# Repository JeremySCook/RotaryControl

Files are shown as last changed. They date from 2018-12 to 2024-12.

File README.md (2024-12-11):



# RotaryControl

*
*
### New Version: Enhanced [JC Pro Macro 2](https://www.tindie.com/products/jeremycook/jc-pro-macro-2-rotarygpio-macro-keyboard-kit/) for sale on Tindie with all kinds of fun features.
*
*

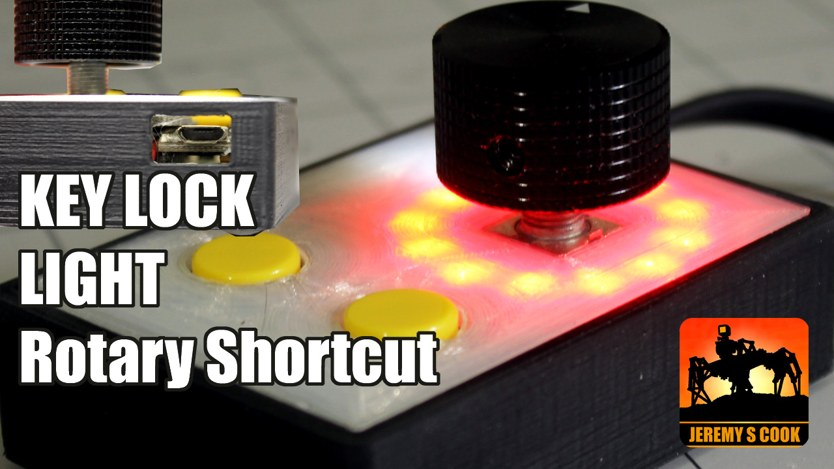
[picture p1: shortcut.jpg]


### Build videos

https://www.youtube.com/playlist?list=PLUSVaS5vtdgQBRD3hqpD_LZi0aTD-GRQe

### Purchased Electronics Needed

5x7 Perf board \
I2C Rotary Encoder: https://www.tindie.com/products/Saimon/i2cencoder-v2-connect-multiple-encoder-on-i2c-bus/ \
MellBell PICO: https://mellbell.cc/products/pico \
NeoPixel Ring: https://www.adafruit.com/product/1643 \
Rotary Encoder \
Encoder knob: https://www.ebay.com/itm/K9-0-25-Dia-Black-Aluminum-Rotary-Control-Potentiometer-Knob-25mm-x-15mm/253315168134 \
Pushbuttons \
Wire

### 3D Print Stuff

Clear PLA https://amzn.to/2MXi3qr (Amazon Affiliate) \
Black PLA https://amzn.to/31PlYd2 (Amazon Affiliate) \
Plasti Dip Spray https://amzn.to/34lU22f (Amazon Affiliate - not sure if this is the correct type)

### Wiring Diagram

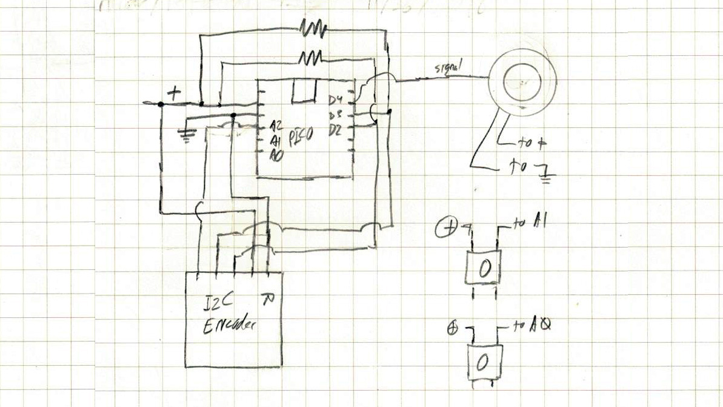
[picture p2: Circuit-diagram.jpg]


### Other Info

This post was helpful to figure out how to use the caps lock functionality: https://www.instructables.com/id/USB-Volume-Control-and-Caps-Lock-LED-Simple-Cheap-/ \
Code referenced in [Arrow Encoder article](https://www.arrow.com/en/research-and-events/articles/rotary-encoders-how-to-pair-with-an-arduino-board): https://github.com/JeremySCook/ArduinoEncoder



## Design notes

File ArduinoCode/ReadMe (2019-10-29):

Arduino Code including two i2c Libraries ((i2cEncoderLibV2.cpp and i2cEncoderLibV2.h)
that need to be placed in same directory as main code.

Rotary-shortcut-1-capslock.ino adds functionality for ring to light up blue when caps lock key is on.

Rotary-shortcut-3-locks-jog.ino gives an indication of caps lock, scroll lock, and num lock.
Does away with game functionality as shown in the demo video, but replaces it with a "jog" function
that adjusts volume up and down intermittently to keep computer awake (in case your power management is
acting screwy).

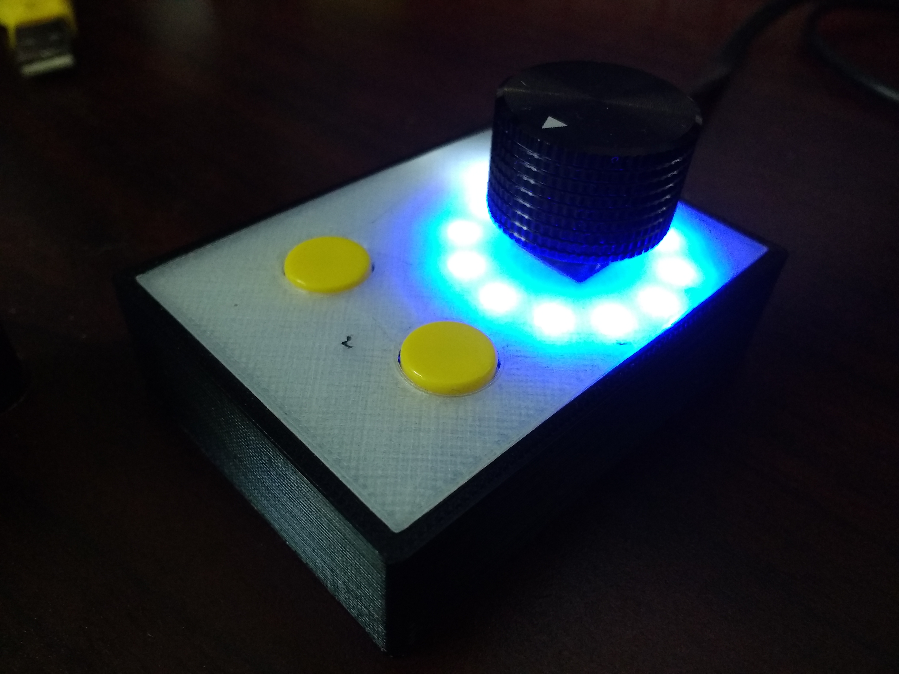
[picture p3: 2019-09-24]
rotary-caps.jpg

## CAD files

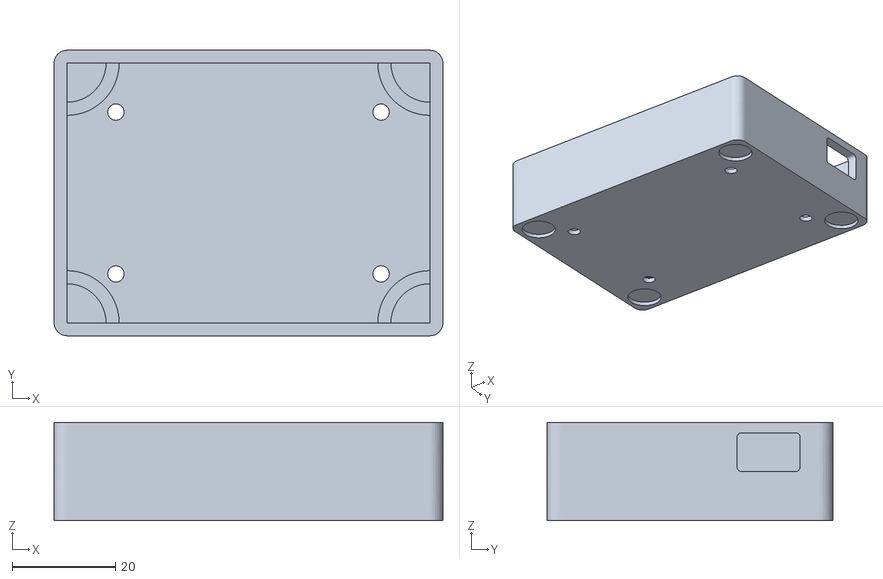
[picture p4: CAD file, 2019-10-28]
STL/shortcut-outer.stl
75.4 x 55.4 x 19.0

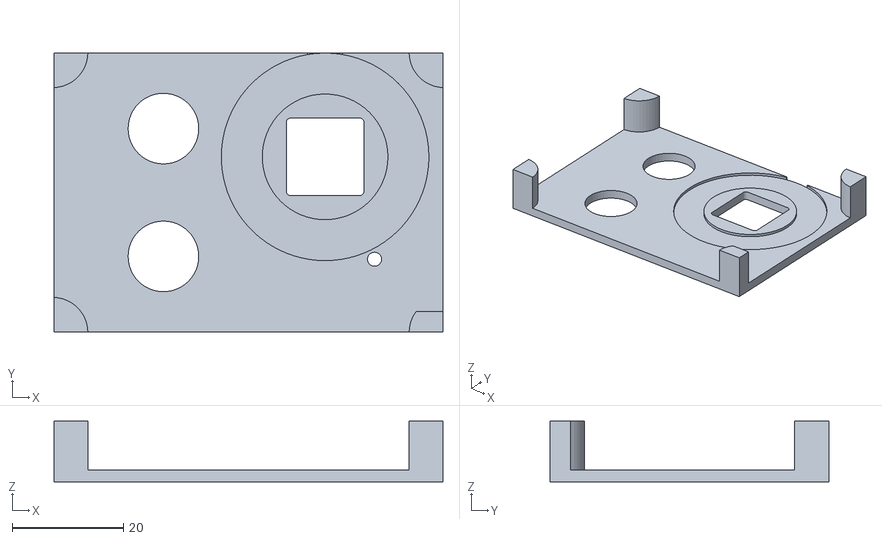
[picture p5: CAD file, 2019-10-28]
STL/shortcut-inner.stl
70.0 x 50.2 x 10.9

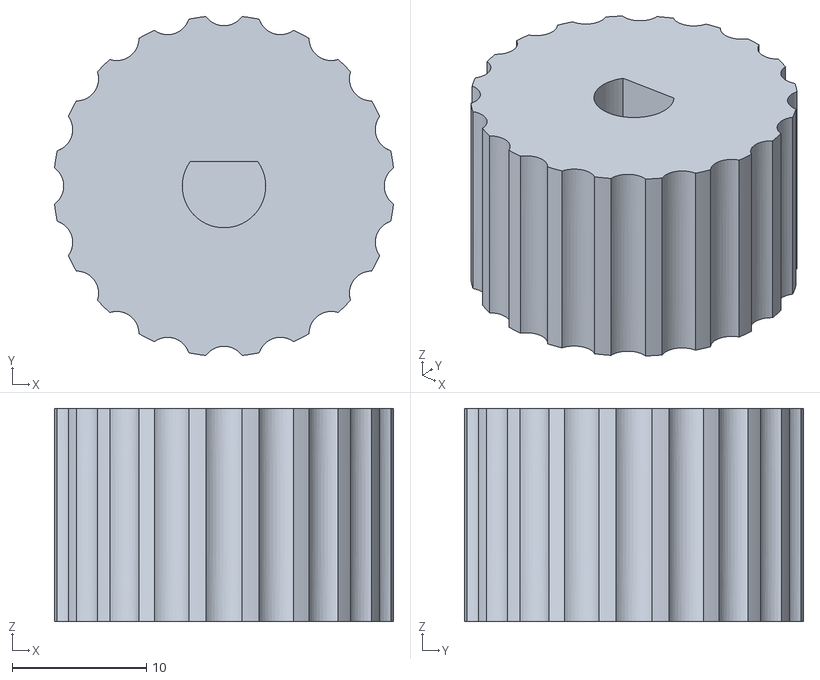
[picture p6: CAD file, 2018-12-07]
STL/Knob.stl
25.3 x 25.3 x 15.9

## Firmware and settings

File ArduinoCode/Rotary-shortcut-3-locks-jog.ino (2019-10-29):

//Need to include i2cEncoderLibV2.cpp and i2cEncoderLibV2.h in same directory

//Initial setup =============================================================================

#include <Wire.h>
#include "i2cEncoderLibV2.h"
#include <Adafruit_NeoPixel.h>
#ifdef __AVR__
#include <avr/power.h>
#endif
#include "HID-Project.h"

#define PINRGB  4
#define NUMPIXELSRGB  12

int xMovements[] = {-3, -8, -14, -16, -19, -19, -16, -14, -8, -3, 3, 8, 14, 16, 19, 19, 16, 14, 8, 3, -3};
int yMovements[] = {19, 16, 14, 8, 3, -3, -8, -14, -16, -19, -19, -16, -14, -8, -3, 3, 8, 14, 16, 19, 19}; 
int controlMode = 0;
int sensorValue;
int sensorValue1;
int brightness = 0;
int interval = 150;
unsigned long jogTime = 60000;
unsigned long previousMillis = 0;
unsigned long previousMillis1 = 0;

i2cEncoderLibV2 Encoder(0x00);
const int IntPin = A2; // Definition of the interrupt pin on PICO

Adafruit_NeoPixel pixelsRGB = Adafruit_NeoPixel(NUMPIXELSRGB, PINRGB, NEO_RGB + NEO_KHZ800);

//End Initial Setup ==========================================================================

void setup() {
  // initialize serial communication at 9600 bits per second:
  Serial.begin(9600);
  pinMode(A0, INPUT_PULLUP); //define analog pin 0 as pullup input
  pinMode(A1, INPUT_PULLUP); //define analog pin 1 as pullup input
  pinMode(IntPin, INPUT); //sets A2 as int pin for I2C encoder
  pixelsRGB.begin(); // This initializes the NeoPixel library as pixelsRGB object.

//setup for encoder
  Encoder.begin(INT_DATA | WRAP_ENABLE | DIRE_LEFT | IPUP_ENABLE | RMOD_X1 | STD_ENCODER);
  Encoder.writeCounter((int32_t)0); /* Reset the counter value */
  Encoder.writeMax((int32_t)19); /* Set the maximum threshold*/
  Encoder.writeMin((int32_t) 0); /* Set the minimum threshold */
  Encoder.writeStep((int32_t)1); /* Set the step to 1*/
  Encoder.writeInterruptConfig(0xff); /* Enable all the interrupt */
  Encoder.writeAntibouncingPeriod(20);  /* Set an anti-bouncing of 200ms */
  Encoder.writeDoublePushPeriod(50);  /*Set a period for the double push of 500ms */

//setup keyboard and mouse input
Mouse.begin();
Keyboard.begin();
}

//Start Main Loop =========================================================================

void loop() {

//caps lock code ==========================================================================

if (BootKeyboard.getLeds() & LED_CAPS_LOCK){
  int pixelNumber = map(Encoder.readCounterByte(), 0, 19, 0, 11);
  Serial.println("capsLock");
  for(int x = 0; x <12; x++){
  pixelsRGB.setPixelColor(x, pixelsRGB.Color(0,0,10)); 
  }
  pixelsRGB.setPixelColor(pixelNumber, pixelsRGB.Color(0,0,10));
  if (pixelNumber != 11) pixelsRGB.setPixelColor(pixelNumber + 1, pixelsRGB.Color(0,10,0));
  if (pixelNumber == 11) pixelsRGB.setPixelColor(0, pixelsRGB.Color(0,10,0));
  if (pixelNumber != 0) pixelsRGB.setPixelColor(pixelNumber - 1, pixelsRGB.Color(0, 10, 0));
  if (pixelNumber == 0) pixelsRGB.setPixelColor(11, pixelsRGB.Color(0, 10, 0));  
  pixelsRGB.show(); // This sends the updated pixel color to the hardware.
}

//scroll lock code =======================================================================

else if (BootKeyboard.getLeds() & LED_SCROLL_LOCK){
  int pixelNumber = map(Encoder.readCounterByte(), 0, 19, 0, 11);
  Serial.println("Scroll Lock");
  for(int x = 0; x <12; x++){
  pixelsRGB.setPixelColor(x, pixelsRGB.Color(10,0,0)); 
  }
  pixelsRGB.setPixelColor(pixelNumber, pixelsRGB.Color(10,0,0));
  if (pixelNumber != 11) pixelsRGB.setPixelColor(pixelNumber + 1, pixelsRGB.Color(0,10,0));
  if (pixelNumber == 11) pixelsRGB.setPixelColor(0, pixelsRGB.Color(0,10,0));
  if (pixelNumber != 0) pixelsRGB.setPixelColor(pixelNumber - 1, pixelsRGB.Color(0, 10, 0));
  if (pixelNumber == 0) pixelsRGB.setPixelColor(11, pixelsRGB.Color(0, 10, 0));  
  pixelsRGB.show(); // This sends the updated pixel color to the hardware.
}

//acts normally if num lock is on and other locks off ===================================

else if (BootKeyboard.getLeds() & LED_NUM_LOCK) {
  int pixelNumber = map(Encoder.readCounterByte(), 0, 19, 0, 11);
  for(int x = 0; x <12; x++){
  pixelsRGB.setPixelColor(x, pixelsRGB.Color(0,0,0)); // Red *red/green may be reversed depending on your strip
  }
  pixelsRGB.setPixelColor(pixelNumber, pixelsRGB.Color(10,0,0));
  if (pixelNumber != 11) pixelsRGB.setPixelColor(pixelNumber + 1, pixelsRGB.Color(0,10,0));
  if (pixelNumber == 11) pixelsRGB.setPixelColor(0, pixelsRGB.Color(0,10,0));
  if (pixelNumber != 0) pixelsRGB.setPixelColor(pixelNumber - 1, pixelsRGB.Color(0, 10, 0));
  if (pixelNumber == 0) pixelsRGB.setPixelColor(11, pixelsRGB.Color(0, 10, 0));  
  pixelsRGB.show(); // This sends the updated pixel color to the hardware.
}

//lights up leds red if no num lock ===============================================================

else {
  int pixelNumber = map(Encoder.readCounterByte(), 0, 19, 0, 11);
  unsigned long currentMillis = millis();
  if(currentMillis - previousMillis > interval){
    brightness +=1;
    previousMillis = millis(); 
  }
  if(brightness > 20){
    brightness = 0;
  }
  int LEDLevel = abs(9-brightness);
  //Serial.println("no num lock");
  for(int x = 0; x <12; x++){
  pixelsRGB.setPixelColor(x, pixelsRGB.Color(0,LEDLevel,0)); 
  }
  pixelsRGB.setPixelColor(pixelNumber, pixelsRGB.Color(0,10,0));
  if (pixelNumber != 11) pixelsRGB.setPixelColor(pixelNumber + 1, pixelsRGB.Color(0,10,0));
  if (pixelNumber == 11) pixelsRGB.setPixelColor(0, pixelsRGB.Color(0,10,0));
  if (pixelNumber != 0) pixelsRGB.setPixelColor(pixelNumber - 1, pixelsRGB.Color(0, 10, 0));
  if (pixelNumber == 0) pixelsRGB.setPixelColor(11, pixelsRGB.Color(0, 10, 0));  
  pixelsRGB.show(); // This sends the updated pixel color to the hardware.
  delay(5);
}

//end NeoPixel lighting code===================================================================

  sensorValue = digitalRead(A0);
  sensorValue1 = digitalRead(A1);
  if (sensorValue == 0 && sensorValue1 == 0 && controlMode == 1) controlMode = 0;
  else if (sensorValue == 0 && sensorValue1 == 0 && controlMode == 0) controlMode = 1;  
  uint8_t enc_cnt; //read encoder input
  //Serial.print("sensorValue ");
  //Serial.println(sensorValue);
  //Serial.print("sensorValue1 ");
  //Serial.println(sensorValue1);
  //Serial.print("EncoderPUSHP ");
  //Serial.println(Encoder.readStatus(PUSHP));
  //Serial.print("controlMode ");
  //Serial.println(controlMode);
  //delay(1);    
  volume();
  if (controlMode == 1) game();
}

void volume() {
  if (digitalRead(IntPin) == LOW) {
    if (Encoder.updateStatus()) {
      if (Encoder.readStatus(RINC)) {
        Serial.print("Increment: ");
        Serial.println(Encoder.readCounterByte());
        Consumer.write(MEDIA_VOLUME_UP);
        delay(1);
      }
    if (Encoder.readStatus(RDEC)) {
        Serial.print("Decrement: ");
        Serial.println(Encoder.readCounterByte());
        Consumer.write(MEDIA_VOLUME_DOWN);
        delay(1);
      }
    if (Encoder.readStatus(PUSHR)) {
        Serial.println("Push button Released");
        delay(1);        
      }

    if (Encoder.readStatus(PUSHP)) {
        Serial.println("Push button Pressed");
        Consumer.write(MEDIA_PLAY_PAUSE);
        delay(1); 
      }
    }
  }
  else if (sensorValue1 == 0){
      Consumer.write(MEDIA_NEXT);
      delay(250);
      
  }
  else if (sensorValue == 0){
      Consumer.write(MEDIA_PREVIOUS);
      delay(250);
  }    
}

void game() {
  unsigned long currentMillis = millis();  
  for(int x = 7; x <9; x++){
  pixelsRGB.setPixelColor(x, pixelsRGB.Color(0,0,12));  
  }
  pixelsRGB.show(); // This sends the updated pixel color to the hardware.
  if(currentMillis - previousMillis1 > jogTime){
  //works well now, could change it to toggle scroll lock on and off to make it even less interesting??
    BootKeyboard.write(KEY_SCROLL_LOCK);
    delay(10);
    BootKeyboard.write(KEY_SCROLL_LOCK);
    previousMillis1 = millis();
  }
}

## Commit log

2018-11-29 Create ButtonReadPullup
2018-11-29 Create ButtonReadPullupRing
2018-11-29 Update ButtonReadPullupRing
